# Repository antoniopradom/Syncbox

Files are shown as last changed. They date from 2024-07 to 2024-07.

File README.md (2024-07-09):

# Syncbox

This is syncbox that was designed to worked with as many devices as possible. It can sync TTL signals, wifi devices, motion capture cameras (e.g. Vicon), video cameras (using red LED). It can be daisy-chained with multiple devices or other syncboxes.

It has 2 operations modes:

1. Main: Receives a high TTL signal, then broadcasts a UDP packet (repeated 5 times for prevent packet loss) that can be captured by any WIFI enabled device. As long as the signal is high, the LEDs will be on. This allows to sync cameras. When the TTL signal goes low, a stop sync UDP packet is sent and the LEDs are turned off.
1. Receiver: When a box set to main mode broadcasts the sync UDP packet, the receiver turns on the LEDs and generates a TTL signal that allows syncing devices that are not WIFI enabled. When the sync end UDP packet is received, the TTL goes low and the LEDs turn off.

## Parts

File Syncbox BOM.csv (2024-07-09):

Part | Qty | Suggested link
Audio Jack 3.5mm | 3 | https://www.sparkfun.com/products/8032
Particle photon | 1
850 nm IR LED | 1 | https://www.mouser.com/ProductDetail/Vishay-Semiconductors/TSHG6210?qs=RzxYCzJDjPWJsu8emn%2F6iw%3D%3D&mgh=1
Red LED | 1
68 ohm | 1
10K ohms | 1
330 ohm | 1
N-Channel Mosfet - SOT-223 | 1

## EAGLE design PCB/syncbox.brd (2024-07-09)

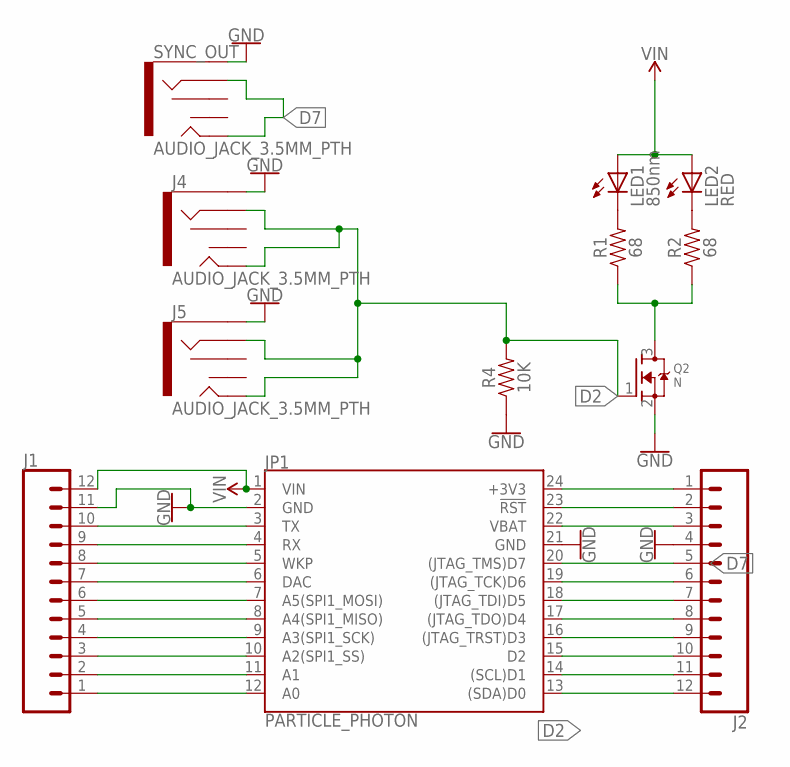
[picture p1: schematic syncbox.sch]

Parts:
J1, J2: CONN_12; 1X12
J4, J5: AUDIO_JACK_3.5MM_PTH; AUDIO-JACK
JP1: PARTICLE_PHOTON
LED1: 850nm; LED5MM
LED2: RED; LED5MM
Q2: N; SOT23-W
R1, R2: 68; AXIAL-0.3
R4: 10K; AXIAL-0.3
SYNC_OUT: AUDIO_JACK_3.5MM_PTH; AUDIO-JACK

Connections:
D2: J2.10, J4.RING, J4.TIP, J5.RING, J5.TIP, JP1.15 (D2), Q2.1 (G), R4.P$2 (2)
D7: J2.5, JP1.20 ((JTAG_TMS)D7), SYNC_OUT.RING, SYNC_OUT.TIP
GND: J1.11, J2.4, J4.SLEEVE, J5.SLEEVE, JP1.2 (GND), JP1.21 (GND), Q2.2 (S), R4.P$1 (1), SYNC_OUT.SLEEVE
unnamed: LED1.K (C), R1.P$2 (2)
unnamed: LED2.K (C), R2.P$2 (2)
unnamed: Q2.3 (D), R1.P$1 (1), R2.P$1 (1)
unnamed: J1.10, JP1.3 (TX)
unnamed: J1.9, JP1.4 (RX)
unnamed: J2.12, JP1.13 ((SDA)D0)
unnamed: J1.8, JP1.5 (WKP)
unnamed: J1.7, JP1.6 (DAC)
unnamed: J1.6, JP1.7 (A5(SPI1_MOSI))
unnamed: J1.5, JP1.8 (A4(SPI1_MISO))
unnamed: J1.4, JP1.9 (A3(SPI1_SCK))
unnamed: J1.3, JP1.10 (A2(SPI1_SS))
unnamed: J1.2, JP1.11 (A1)
unnamed: J1.1, JP1.12 (A0)
unnamed: J2.11, JP1.14 ((SCL)D1)
unnamed: J2.9, JP1.16 ((JTAG_TRST)D3)
unnamed: J2.8, JP1.17 ((JTAG_TDO)D4)
unnamed: J2.7, JP1.18 ((JTAG_TDI)D5)
unnamed: J2.6, JP1.19 ((JTAG_TCK)D6)
unnamed: J2.3, JP1.22 (VBAT)
unnamed: J2.2, JP1.23 (!RST!)
unnamed: J2.1, JP1.24 (+3V3)
VIN: J1.12, JP1.1 (VIN), LED1.A, LED2.A

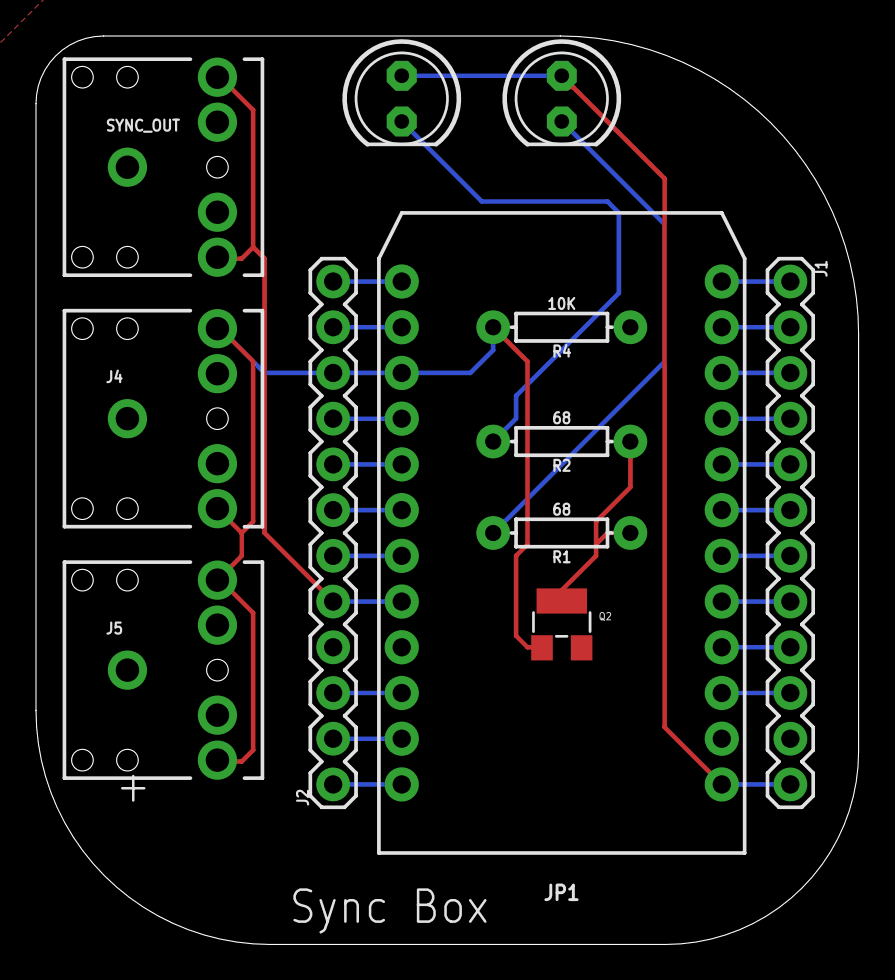
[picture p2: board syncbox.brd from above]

Board: 2 copper layers, 45.7 x 50.5 mm, 12 parts (0 on the bottom side), 26 nets.

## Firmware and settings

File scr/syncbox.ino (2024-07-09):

 #define UDP_Rx_Size 512 //the size of the receive (Rx) UDP array that we
                               //use to store incoming data.
                               

int button = D2;                      // button is connected to D0
int LED = D7;                         // LED is connected to D1
unsigned int localPort = 12354;
char buffer[] = {0xA, 0xD, 0xA, 0xC, 0x0, 0xC, 0xD, 0xF};
UDP Udp;
IPAddress broadcast(255, 255, 255, 255);
int c = 0;
int d = 0;
const int numerSend = 3;
bool sendSync = true;
bool onByUDP = false;

static IPAddress senderIPAddress; //the IP address of the sender, from the last received data packet
static uint8_t UDP_Rx[UDP_Rx_Size]; //the UDP buffer for incoming data
static int senderPort; //the port of the sender, from the last received data packet


SYSTEM_MODE(MANUAL); //manual mode means the Photon does NOT automatically connect to the cloud, and we have to establish connnectivity and maintain it with calls to Particle.process(). We

void setup()
{
    WifiSetup();
  pinMode(LED, OUTPUT);               // sets pin as output
  pinMode(button, INPUT_PULLDOWN );    // sets pin as input
  Udp.begin(localPort);
}

void loop()
{
  // blink the LED as long as the button is pressed
  if (!onByUDP){
      if(digitalRead(button) == HIGH) {
          d = 0;
        digitalWrite(LED, HIGH);          // sets the LED on
        if (sendSync){
            buffer[4] = 0x1;
            if (Udp.sendPacket(buffer, 7, broadcast, localPort) < 0) {
               Particle.publish("Error");
               digitalWrite(LED, LOW); 
            }
            c++;
            if (c>=numerSend){
                sendSync=false;
                c = 0;
            }
        }
      }else{
        
        //sendSync = true;
        if (!sendSync){
            buffer[4] = 0x0;
            if (Udp.sendPacket(buffer, 7, broadcast, localPort) < 0) {
               Particle.publish("Error");
               digitalWrite(LED, LOW); 
            }
            d++;
            if (d>=numerSend){
                sendSync=true;
                d = 0;
            }
        }
        c = 0;
        digitalWrite(LED, LOW);           // sets the LED off
        
      }
  }
  checkForReceivedUDPData();
}
/*
void WifiSetup() {

  IPAddress myAddress(192,168,0,125);
  IPAddress netmask(255,255,255,0);
  IPAddress gateway(192,168,0,1);
  IPAddress dns(192,168,0,1);
  WiFi.setStaticIP(myAddress, netmask, gateway, dns);

  // now let's use the configured IP
  WiFi.useStaticIP();
  WiFi.connect(); //use stored credentials (loaded onto the Particle Photon) to try to connect to WiFi
  while(!WiFi.ready()){;} //block until this Photon has been assigned an IP address. We may need to do this on a Local Area Network.
}*/

void WifiSetup(/* arguments */) {
  int lasDir;
  // if(IAMLEFT==1){
  //   lasDir = 102;
  // } else {
  //   lasDir = 103;
  // }
  // IPAddress myAddress(192,168,0,lasDir);
  // IPAddress netmask(255,255,255,0);
  // IPAddress gateway(192,168,0,1);
  // IPAddress dns(192,168,0,1);
  // WiFi.setStaticIP(myAddress, netmask, gateway, dns);
  //
  // // now let's use the configured IP
  // WiFi.useStaticIP();
  WiFi.useDynamicIP();
  WiFi.connect(); //use stored credentials (loaded onto the Particle Photon) to try to connect to WiFi
  while(!WiFi.ready()){;} //block until this Photon has been assigned an IP address. We may need to do this on a Local Area Network.
}

void checkForReceivedUDPData() {


  // Check if UDP data has been received
  uint16_t receivedPacketSize = Udp.parsePacket(); // prepares the packet to be read, and returns the size of the packet

  if (receivedPacketSize > 0) { //if we do have UDP data waiting to be read
    //respond to received UDP data
                //digitalWrite(LED, HIGH);

    readIncomingUDPData(receivedPacketSize); //read incoming UDP data from buffer
    interpretReceivedUDPData(receivedPacketSize); //take any necessary action from incoming UDP data
  }
}

/*

Function: readIncomingUDPData()

Parameters: none

Returns: none

Description: Reads UDP data sent from the master shoe Photon. Stores the data in
the UDP_Rx buffer.

Notes:

*/
void readIncomingUDPData(uint16_t receivedPacketSize){

  // Store sender ip and port
  senderIPAddress = Udp.remoteIP();
  senderPort = Udp.remotePort();

  // Read in all waiting data from the UDP buffer
  while(Udp.available()) { //if there is still data in the Rx UDP buffer
    Udp.read(UDP_Rx, receivedPacketSize); //read a character into the Rx buffer
  }

} //end readIncomingUDPData()



/*

Function: interpretReceivedUDPData()

Parameters: none

Returns: none

Description: Responds to incoming UDP data

Notes:

*/
void interpretReceivedUDPData(uint16_t receivedPacketSize){
    
    if((UDP_Rx[0]==0xA) & (UDP_Rx[1]==0xD) & (UDP_Rx[2]==0xA) & (UDP_Rx[3]==0xC)){ //if this UDP data packet is from the "master" microcontroller or PC
        digitalWrite(LED, UDP_Rx[4]==1);
        onByUDP = UDP_Rx[4]==1;
        //digitalWrite(LED, HIGH);
    } 
}

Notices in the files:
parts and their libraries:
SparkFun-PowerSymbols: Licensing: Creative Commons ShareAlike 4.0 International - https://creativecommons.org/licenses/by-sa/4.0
